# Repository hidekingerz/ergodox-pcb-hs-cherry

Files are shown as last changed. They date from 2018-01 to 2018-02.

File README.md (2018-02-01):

# ergodox-pcb-hs-cherry

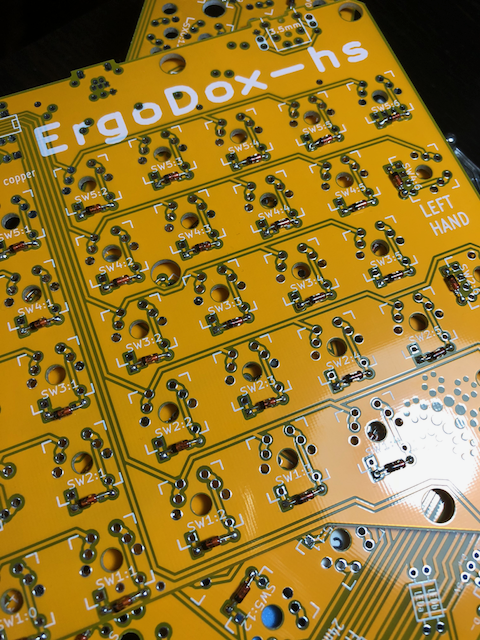
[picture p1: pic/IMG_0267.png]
PCB pcb


Holtite Socket対応版Ergodox PCBデータです。  
以下のリポジトリを元に変更しています。

https://github.com/bishboria/ErgoDox

[Build-Logはこちら](https://gist.github.com/hidekingerz/674485b1bc5f276b9785774917839918)です。

# はじめに
はんだ付け無しでキースイッチとTeensy2を設置できる基板です。
IOエキスパンダと各種抵抗、I/Fは対応していません。

なお、実際に組み立てて動作するところは確認していますが、LEDは趣味ではないのでLED点灯のみ動作確認をしていません。

## 対応Holtite Socket
以下のどちらかに対応しています。

- [8134-HC-8P2](http://www.te.com/jpn-ja/product-7-1437514-0.html)  
- [8134-HC-8P3](http://www.te.com/jpn-ja/product-7-1437514-1.html)

## 必要な部品
|パーツ|リンク|量|
|:---|:---|:---|
|PCB|	-	|2|
|Teensy USB Board, Version 2.0|http://www.pjrc.com |1|
|MCP23018 I/O expander|Digikey: MCP23018-E/SP-ND|1|
|3.5mm TRRS connector|Digikey: CP-43514-ND|2|
|USB mini B connector|Digikey: WM17115-ND|1|
|USB mini B plug|Digikey: H2955-ND|1|
|0.1 UF ceramic capacitor|Digikey: BC2665CT-ND*|1|
|1N4148 diode (SOD-123 package (SMD), or DO-35 (through hole 0.3" pitch))|Digikey: 1N4148FS-ND* or Digikey: 1N4148W-FDICT-ND*	|76-80|
|2.2K Ω resistor|Digikey: 2.2KQTR-ND*|2|
|3mm T1 LED|Digikey: 160-1034-ND*| |
|220 Ω resistor (match to led)	|Digikey: 220QBK-ND*|3|
|Cherry MX switch|Mouser: MX1A-*****|76-80|
|USB cable Male A to male mini B|USBFirewire: www.usbfirewire.com*|	1|
|TRRS cable	|MyCableMart: www.mycablemart.com*|1|
|holtite|Digikey:A114359-ND or A114358-ND| (152-160) + 24|

## PCBの入手方法
ご自身でGerberファイルを生成し、PCBGOGO等の基盤制作業者にご依頼ください。

# 実装

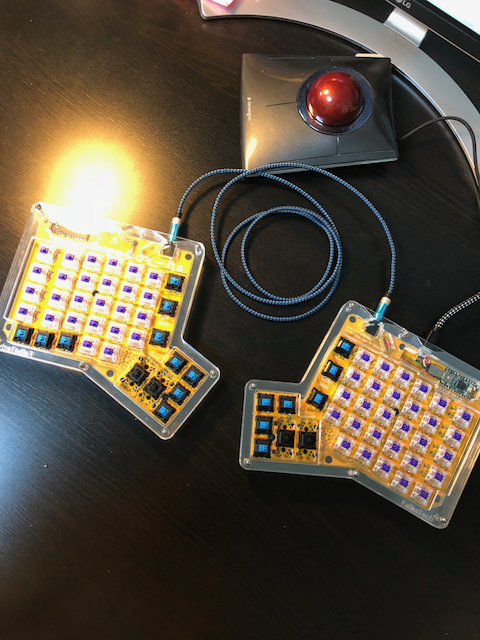
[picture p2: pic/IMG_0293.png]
完成


組み立て方法は通常のErgodoxと変わりません。HoltiteSocketをスルーホールに圧着するところが通常版との違いになります。

## Holtite socketの圧着方法
下記動画を参考にしてください。

(https://www.youtube.com/watch?v=RB1Wm8y2Cw8)

## 取付時の注意点
以下を参照

### IOエキスパンダははんだ付けする
IOエキスパンダを取り付けるスルーホールはHoltiteSocket適合サイズに変更していますが、IOエキスパンダの脚が細すぎて適合しません。

HoltiteSocketは利用せず、通常通り半田付けしてください。

### Falbatechのアクリルキースイッチプレートを利用した場合の適合表

Falbatechのアクリルケースについているスイッチプレートを使用した場合、厚みによりMX互換品のキースイッチでも高さが足りずに接触できない種類のものが有りました。
メタルのスイッチプレートを利用している方はどのスイッチでも使えると思います。

|メーカー|種類|結果|
|:---|:---|:---|
|CheeryMX|黒軸|OK|
||青軸|OK|
||赤軸|OK|
|ZealPC|R9 Purple Zealio Switches|OK|
|Kaihua|Kailh Speed Switches|NG|

# Special Thanks
[haru-akeさんの HoltiteSocket対応版Let'sSplit](https://github.com/haru-ake/lets-split-pcb-hs-cherry)のPCBを頂いたことから本プロジェクトが始まりました。

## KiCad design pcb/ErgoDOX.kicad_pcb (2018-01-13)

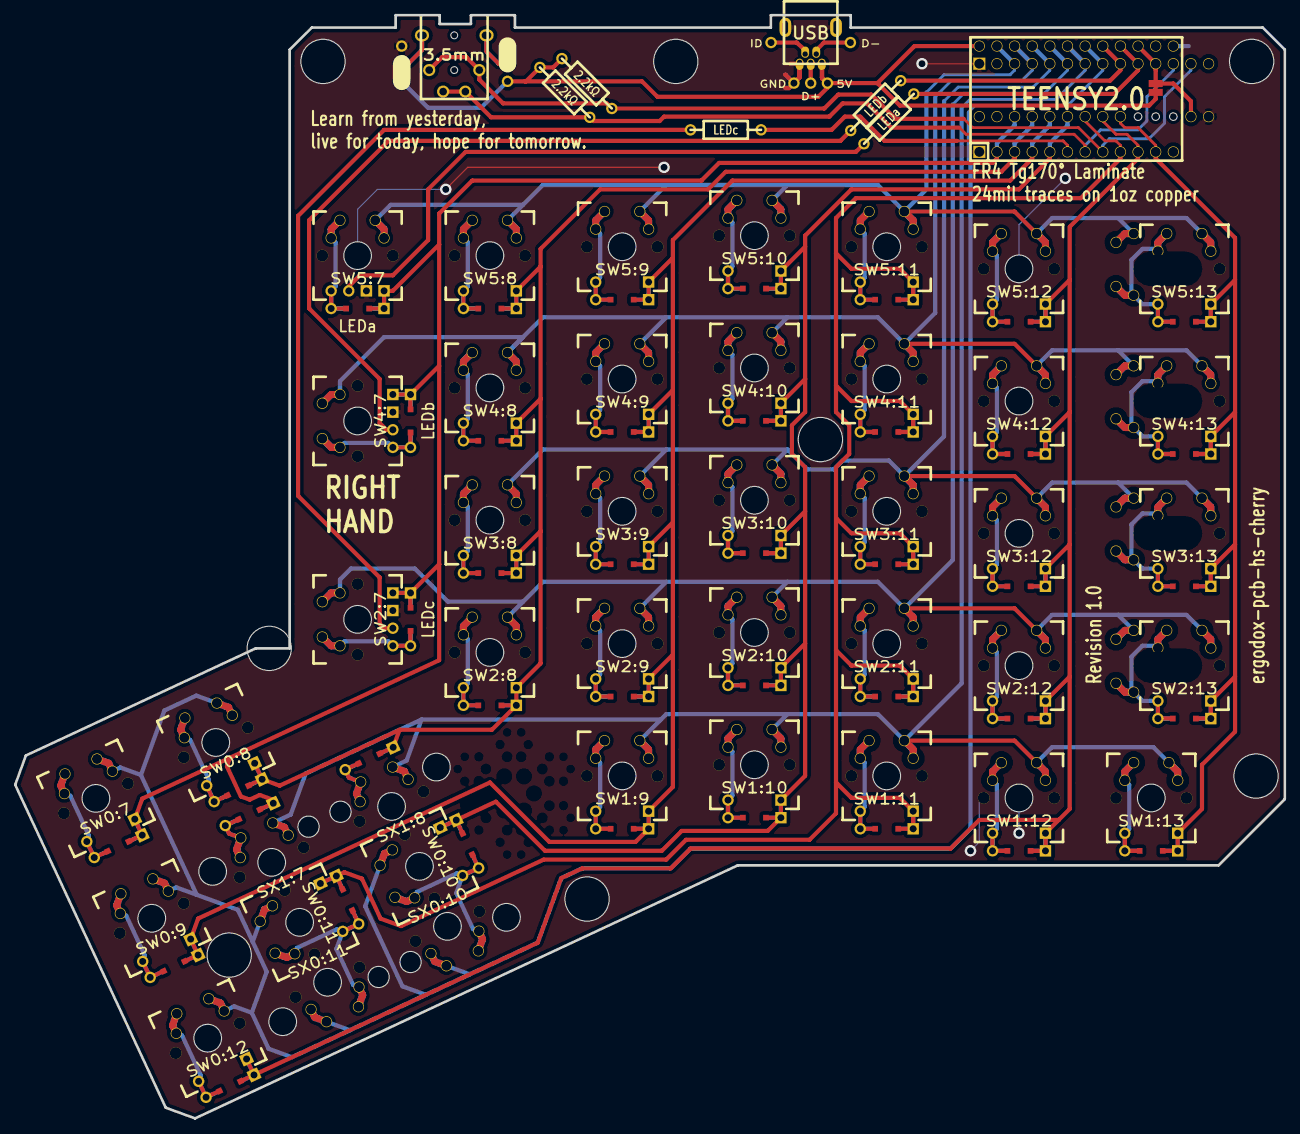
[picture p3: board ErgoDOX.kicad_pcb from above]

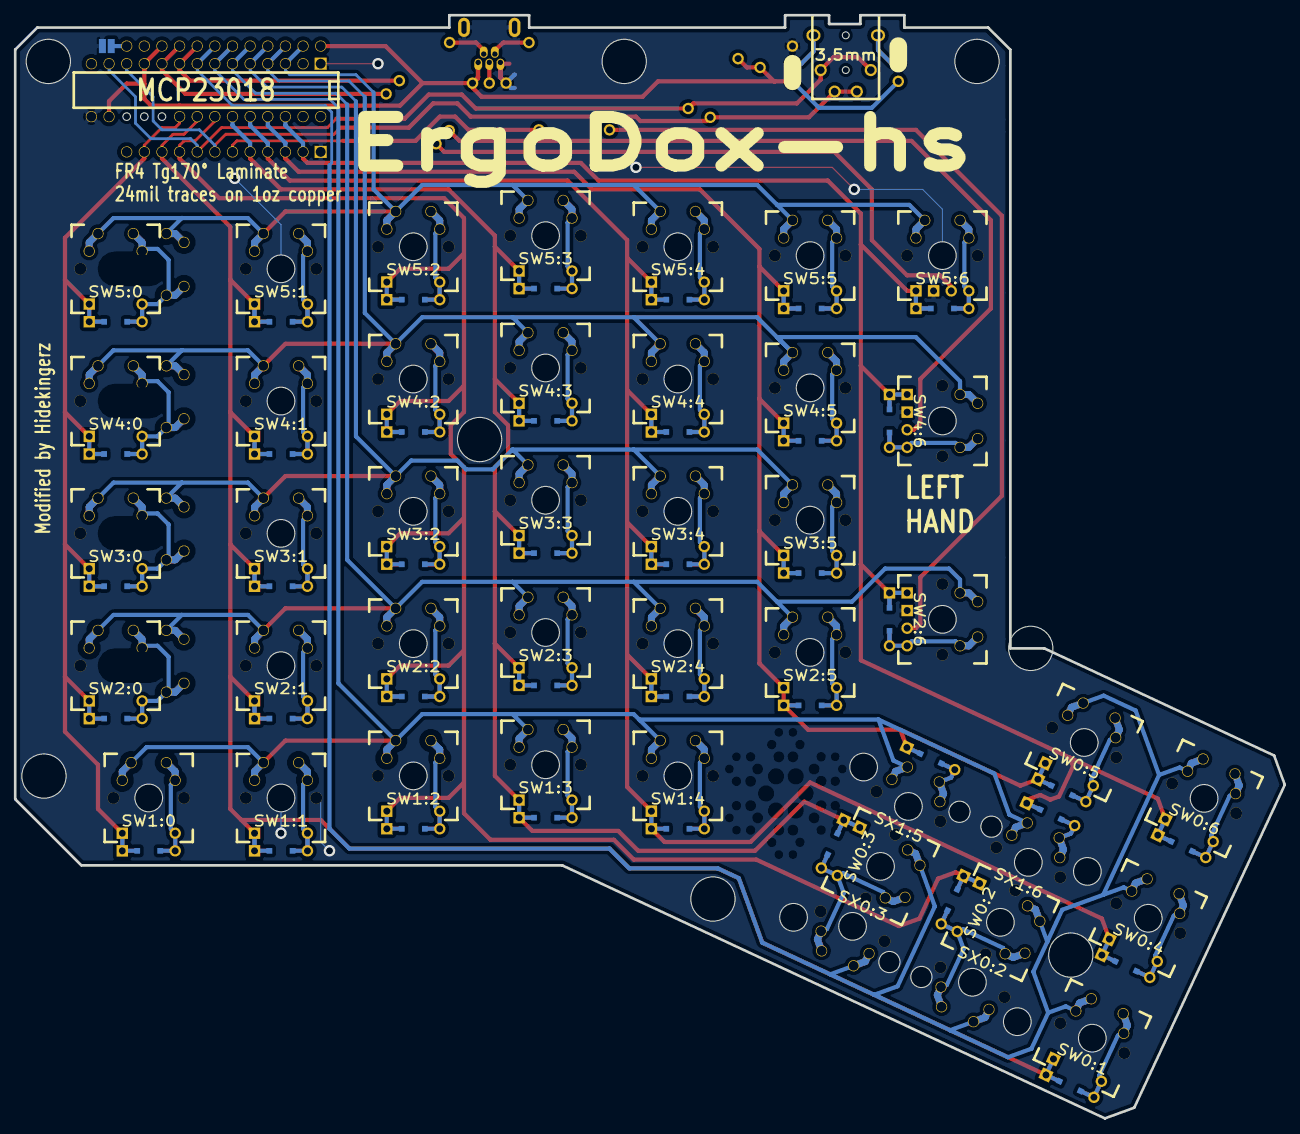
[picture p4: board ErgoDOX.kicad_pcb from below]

Board: 2 copper layers, 182.8 x 158.9 mm, 63 parts (3 on the bottom side), 65 nets.

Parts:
D1:7, D1:8: D; DIODE
H99: MECHANICAL; ErgoDOXmech
J1: USB; USBMINImod
J2: 3.5mm; 4pin35mmAudio
J3, J4: JMP; 100PITCH1X3
JP1, JP2: JUMPER; GAP
LED_A1: LEDa; MX_LED
LED_B1: LEDb; MX_LED
LED_C1: LEDc; MX_LED
R1, R2: 2.2kΩ; RESISTOR
RA1: LEDa; RESISTOR
RB1: LEDb; RESISTOR
RC1: LEDc; RESISTOR
S1, S2: STAB200; STAB_PCB940
SW0:7: SW0:6; MX_FLIP_DIODE
SW0:8: SW0:5; MX_FLIP_DIODE
SW0:9: SW0:4; MX_FLIP_DIODE
SW0:10: SW0:3; MX_FLIP_DIODE
SW0:11: SW0:2; MX_FLIP_DIODE
SW0:12: SW0:1; MX_FLIP_DIODE
SW1:9: SW1:4; MX_FLIP_DIODE
SW1:10: SW1:3; MX_FLIP_DIODE
SW1:11: SW1:2; MX_FLIP_DIODE
SW1:12: SW1:1; MX_FLIP_DIODE
SW1:13: SW1:0; MX_FLIP_DIODE
SW2:7: SW2:6; MX_FLIP_DIODE
SW2:8: SW2:5; MX_FLIP_DIODE
SW2:9: SW2:4; MX_FLIP_DIODE
SW2:10: SW2:3; MX_FLIP_DIODE
SW2:11: SW2:2; MX_FLIP_DIODE
SW2:12: SW2:1; MX_FLIP_DIODE
SW2:13: SW2:0; MX_FLIP_XX
SW3:8: SW3:5; MX_FLIP_DIODE
SW3:9: SW3:4; MX_FLIP_DIODE
SW3:10: SW3:3; MX_FLIP_DIODE
SW3:11: SW3:2; MX_FLIP_DIODE
SW3:12: SW3:1; MX_FLIP_DIODE
SW3:13: SW3:0; MX_FLIP_XX
SW4:7: SW4:6; MX_FLIP_DIODE
SW4:8: SW4:5; MX_FLIP_DIODE
SW4:9: SW4:4; MX_FLIP_DIODE
SW4:10: SW4:3; MX_FLIP_DIODE
SW4:11: SW4:2; MX_FLIP_DIODE
SW4:12: SW4:1; MX_FLIP_DIODE
SW4:13: SW4:0; MX_FLIP_XX
SW5:7: SW5:6; MX_FLIP_DIODE
SW5:8: SW5:5; MX_FLIP_DIODE
SW5:9: SW5:4; MX_FLIP_DIODE
SW5:10: SW5:3; MX_FLIP_DIODE
SW5:11: SW5:2; MX_FLIP_DIODE
SW5:12: SW5:1; MX_FLIP_DIODE
SW5:13: SW5:0; MX_FLIP_XX
SX0:10: SX0:3; MX_FLIP
SX0:11: SX0:2; MX_FLIP
SX1:7: SX1:6; MX_FLIP
SX1:8: SX1:5; MX_FLIP
U1: TEENSY2.0; TEENSY_2.0
U2: MCP23018; DIP28_300

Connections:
/COL0: SW1:13.4, SW2:13.4, SW3:13.4, SW4:13.4, SW5:13.4, U1.11, U2.20
/COL1: SW0:12.4, SW1:12.4, SW2:12.4, SW3:12.4, SW4:12.4, SW5:12.4, U1.10, U2.21
/COL4: SW0:9.4, SW1:9.4, SW2:9.4, SW3:9.4, SW4:9.4, SW5:9.4, U1.4, U2.24
/COL5: D1:8.2, SW0:8.4, SW2:8.4, SW3:8.4, SW4:8.4, SW5:8.4, U1.3, U2.25
/COL6: D1:7.2, SW0:7.4, SW2:7.4, SW4:7.4, SW5:7.4, U1.2, U2.26
/COL10: SW0:10.4, SW1:10.4, SW2:10.4, SW3:10.4, SW4:10.4, SW5:10.4, U1.5, U2.23
/COL11: SW0:11.4, SW1:11.4, SW2:11.4, SW3:11.4, SW4:11.4, SW5:11.4, U1.9, U2.22
/LED_A: RA1.1, U1.21
/LED_B: RB1.1, U1.22
/LED_C: RC1.1, U1.6
/ROW0: SW0:7.1, SW0:8.1, SW0:9.1, SW0:10.1, SW0:11.1, SW0:12.1, SX0:10.1, SX0:11.1, U1.23, U2.8
/ROW1: SW1:9.1, SW1:10.1, SW1:11.1, SW1:12.1, SW1:13.1, SX1:7.1, SX1:8.1, U1.24, U2.7
/ROW2: SW2:7.1, SW2:8.1, SW2:9.1, SW2:10.1, SW2:11.1, SW2:12.1, SW2:13.1, U1.25, U2.6
/ROW3: SW3:8.1, SW3:9.1, SW3:10.1, SW3:11.1, SW3:12.1, SW3:13.1, U1.26, U2.5
/ROW4: SW4:7.1, SW4:8.1, SW4:9.1, SW4:10.1, SW4:11.1, SW4:12.1, SW4:13.1, U1.27, U2.4
/ROW5: SW5:7.1, SW5:8.1, SW5:9.1, SW5:10.1, SW5:11.1, SW5:12.1, SW5:13.1, U1.28, U2.3
/SCLM: J2.3, J2.5, R2.2, U1.7, U2.12
/SDAM: J2.2, J2.6, R1.2, U1.8, U2.13
GND: H99.0, J1.5, J1.6, J3.3, J4.3, JP2.1, LED_A1.2, LED_B1.2, LED_C1.2, S1.0, S2.0, SW0:7.0, SW0:8.0, SW0:9.0, SW0:10.0, SW0:11.0, SW0:12.0, SW1:9.0, SW1:10.0, SW1:11.0, SW1:12.0, SW1:13.0, SW2:7.0, SW2:8.0, SW2:9.0, SW2:10.0, SW2:11.0, SW2:12.0, SW2:13.0, SW3:8.0, SW3:9.0, SW3:10.0, SW3:11.0, SW3:12.0, SW3:13.0, SW4:7.0, SW4:8.0, SW4:9.0, SW4:10.0, SW4:11.0, SW4:12.0, SW4:13.0, SW5:7.0, SW5:8.0, SW5:9.0, SW5:10.0, SW5:11.0, SW5:12.0, SW5:13.0, SX0:10.0, SX0:11.0, SX1:7.0, SX1:8.0, U1.1, U1.18, U2.1, U2.15
unnamed: J2.4, J4.2
unnamed: J2.1, J3.2
unnamed: SW5:12.2, SW5:12.3
unnamed: SW5:8.2, SW5:8.3
unnamed: SW5:7.2, SW5:7.3
unnamed: D1:8.1, SX1:8.2
unnamed: SW5:9.2, SW5:9.3
unnamed: SW5:10.2, SW5:10.3
unnamed: SW5:11.2, SW5:11.3
unnamed: SW1:9.2, SW1:9.3
unnamed: SW0:10.2, SW0:10.3, SX0:10.2
unnamed: D1:7.1, SX1:7.2
unnamed: SW2:10.2, SW2:10.3
unnamed: SW3:9.2, SW3:9.3
unnamed: SW3:8.2, SW3:8.3
unnamed: SW2:7.2, SW2:7.3
unnamed: SW2:8.2, SW2:8.3
unnamed: SW2:9.2, SW2:9.3
unnamed: SW2:11.2, SW2:11.3
unnamed: SW1:11.2, SW1:11.3
unnamed: SW1:10.2, SW1:10.3
unnamed: SW2:12.2, SW2:12.3
unnamed: SW5:13.2, SW5:13.3
unnamed: SW4:9.2, SW4:9.3
unnamed: SW4:11.2, SW4:11.3
unnamed: SW4:12.2, SW4:12.3
unnamed: SW2:13.2, SW2:13.3
unnamed: SW4:13.2, SW4:13.3
unnamed: SW3:13.2, SW3:13.3
unnamed: SW3:12.2, SW3:12.3
unnamed: SW3:11.2, SW3:11.3
unnamed: SW3:10.2, SW3:10.3
unnamed: SW0:8.2, SW0:8.3
unnamed: SW1:13.2, SW1:13.3
unnamed: SW1:12.2, SW1:12.3
unnamed: SW0:12.2, SW0:12.3
unnamed: SW0:9.2, SW0:9.3
unnamed: SW0:7.2, SW0:7.3
unnamed: SW4:7.2, SW4:7.3
unnamed: SW4:8.2, SW4:8.3
unnamed: SW4:10.2, SW4:10.3
unnamed: LED_C1.1, RC1.2
unnamed: LED_B1.1, RB1.2
unnamed: LED_A1.1, RA1.2
unnamed: SW0:11.2, SW0:11.3, SX0:11.2
VCC: J1.1, J3.1, J4.1, JP1.1, R1.1, R2.1, U1.20, U1.29, U2.11, U2.16

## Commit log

2018-01-10 add data
    kicad data
    [ErgoDOX-B.Mask.gbr, ErgoDOX-B.SilkS.gbr, ErgoDOX-B_Mask.gbs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]
2018-01-10 rm file
    不必要なガーバーファイルを削除。
    [ErgoDOX-B_Mask.gbs, ErgoDOX-B_SilkS.gbo, ErgoDOX-Back.gbl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]
2018-01-12 修正
    Gerberファイルを削除。
    Teensy2とIOエキスパンダもソケット対応。
    [ErgoDOX-B.Mask.gbr, ErgoDOX-B.SilkS.gbr, ErgoDOX-Back.gbr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]
2018-01-13 ファイル整理
    garberファイルを削除
    [ErgoDOX.kicad_pcb]
2018-01-13 mod README
    READMEを修正
2018-01-28 add image
    イメージを追加
    後でちゃんとしたカメラで撮る。
2018-01-28 README ファイルの微修正
    テーブル等々を修正
2018-01-28 HoltiteSockeのDigikeyの品番を追記
    追記した
2018-01-28 add SpecialThanks
    haru-akeさんの事を追記
2018-01-28 完成版の写真を追加
    add pic
2018-02-01 ビルドログを追加
    ・タイトルタイポを修正
    ・ビルドログを追加
